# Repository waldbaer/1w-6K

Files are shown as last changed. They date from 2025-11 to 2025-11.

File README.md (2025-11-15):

# 1-Wire 6-Channel Binary Input Board using DS2411

A compact PCB providing six independent binary input channels on a 1-Wire bus, each based on a dedicated [DS2411](doc/ds2411.pdf) unique-ID device.
Prepared for use in standard 35 mm DIN-rail mounting enclosures.

## Hardware

### Schematic

see [1w-6K_schematic.pdf](doc/1w-6K_schematic.pdf).

### Rendering / Photo

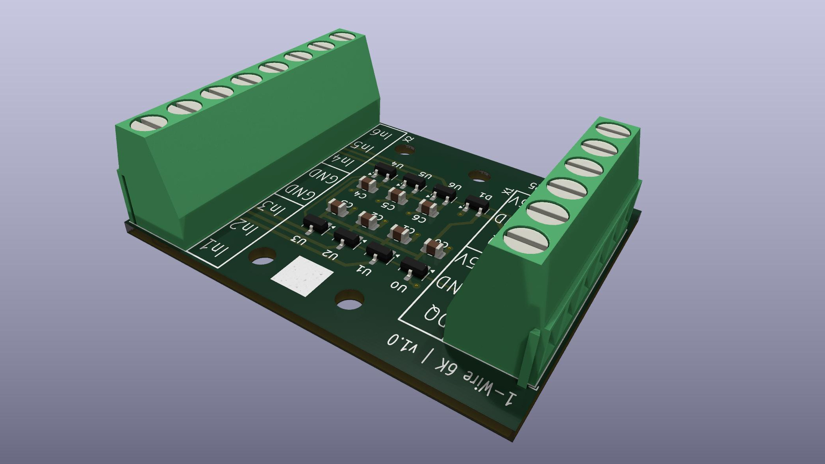
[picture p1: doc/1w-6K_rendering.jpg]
1w-6K rendering

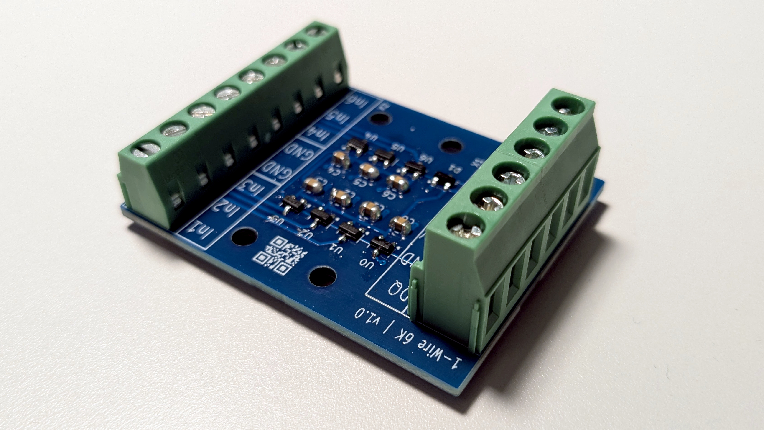
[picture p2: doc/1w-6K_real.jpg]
1w-6K photo


### DIN-rail mounting

The PCB can be mounted to standard 35mm DIN rails using common _25mm DIN Rail Mounting Adapter_ with hole spacing of **12.5mm**.

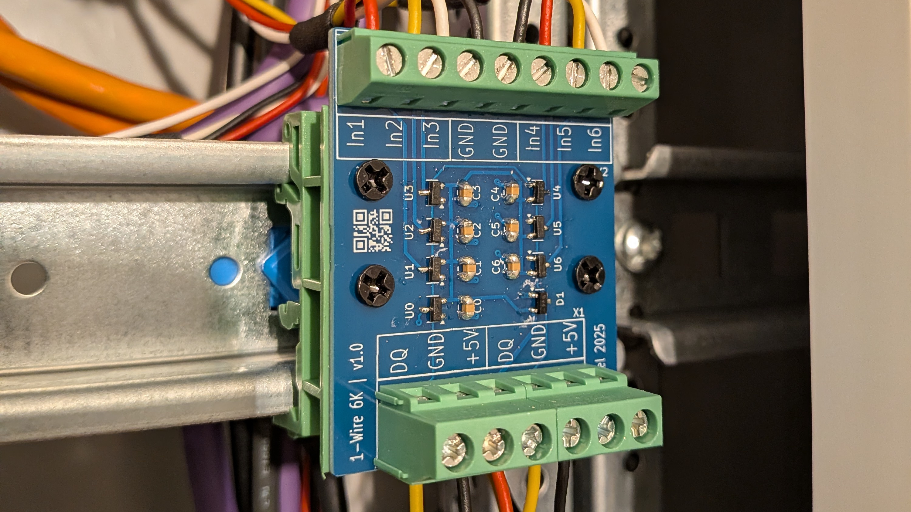
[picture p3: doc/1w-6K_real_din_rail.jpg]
1w-6K photo DIN rail


## Key Features

* 6 × DS2411 devices connected to a the 1-Wire bus
  * Each DS2411 has its GND routed to an individual screw terminal.
  * A binary input channel is considered “closed” when its DS2411 (with factory-programmed 64-bit ROM ID) becomes visible on the bus.

* 1 additional DS2411 permanently connected to the bus.
  * Can be used for alive checks or bus identification

## How It Works

Each binary input corresponds to the GND line of one DS2411.
When GND is connected externally:

* The DS2411 becomes electrically active.
* Its globally unique 64-bit ID appears on the 1-Wire bus.
* The host system interprets this as input active / closed.

### Typical use cases

* Window open / closed detection
* Presence / absence detection

## Development

- PCB designed with [KiCad](https://www.kicad.org/)
- Production files created with KiCad plugin [KiCAD JLCPCB tools](https://github.com/Bouni/kicad-jlcpcb-tools)

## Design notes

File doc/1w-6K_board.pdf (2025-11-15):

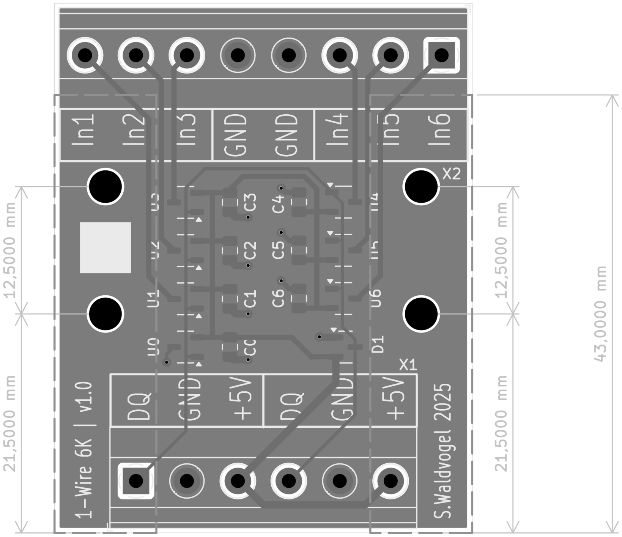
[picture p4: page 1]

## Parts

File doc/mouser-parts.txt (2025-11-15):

Amount  Total Price (EUR)	Single Price (EUR)    Mouser-Nr.:	        Articel Nr.:	    Description.:
15	    € 1,54	          € 1,54                700-DS2411RT&R	    DS2411R+T&R	      Sicherheits-/Authentifizierungs-ICs Sicherheits-/Authentifizierungs-ICs Silicon Serial Number with VCC Input
10	    € 0,071   	      € 0,071               771-BAT54S-T/R	    BAT54S,215	      Schottky Dioden & Gleichrichter Schottky Dioden & Gleichrichter BAT54S/SOT23/TO-236AB
20	    € 0,186   	      € 0,186               581-KAM21KR72A104KU	KAM21KR72A104KU	  Kondensator aus mehreren Keramikschichten MLCC - SMD/SMT Kondensator aus mehreren Keramikschichten MLCC
6	      € 1,18	          € 1,18                651-1890976	        1890976	          Feste Anschlussblöcke Feste Anschlussblöcke 3P 5mm 90DEG
2	      € 3,71	          € 3,71                651-1729076	        1729076	          Feste Anschlussblöcke Feste Anschlussblöcke 8P 5mm 90DEG
6	      € 2,65	          € 2,65                651-3214663	        3214663	          DIN-Schienenanschlussblöcke DIN-Schienenanschlussblöcke PTTBS 1,5/S-KNX
4	      € 0,618   	      € 0,618               651-3214664	        3214664	          Anschlussblocktools und Zubehör Anschlussblocktools und Zubehör D-PTTBS 1,5/S-KNX
2	      € 0,827   	      € 0,827               651-3214699	        3214699	          Anschlussblocktools und Zubehör Anschlussblocktools und Zubehör D-PTTBS 1,5/S
2	      € 0,979   	      € 0,979               651-3022276	        3022276	          Anschlussblocktools und Zubehör Anschlussblocktools und Zubehör CLIPFIX 35-5

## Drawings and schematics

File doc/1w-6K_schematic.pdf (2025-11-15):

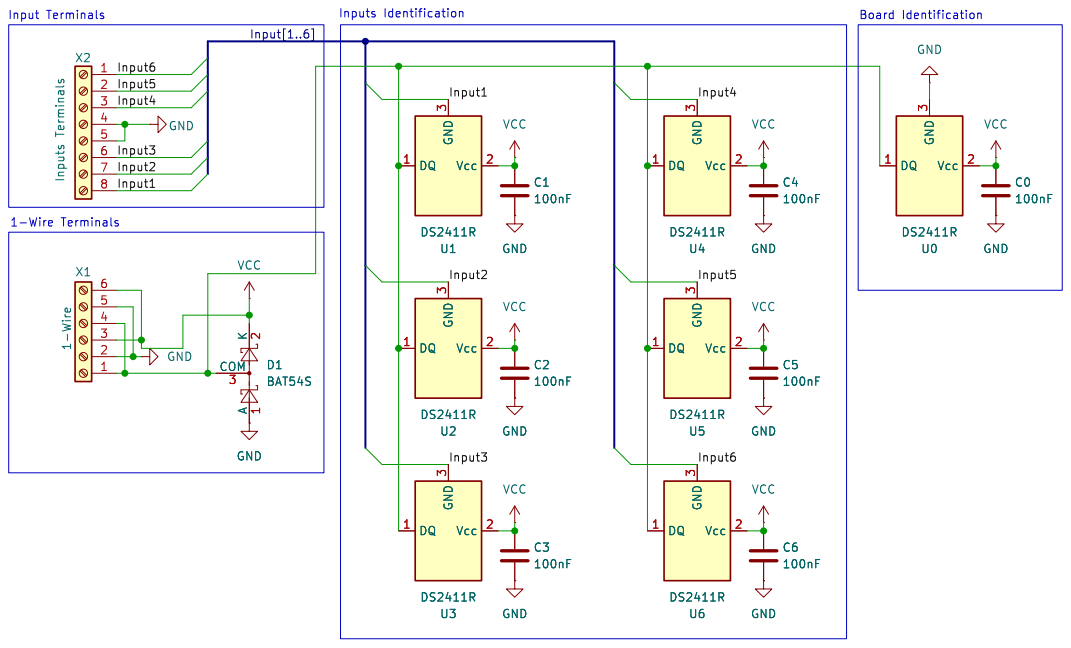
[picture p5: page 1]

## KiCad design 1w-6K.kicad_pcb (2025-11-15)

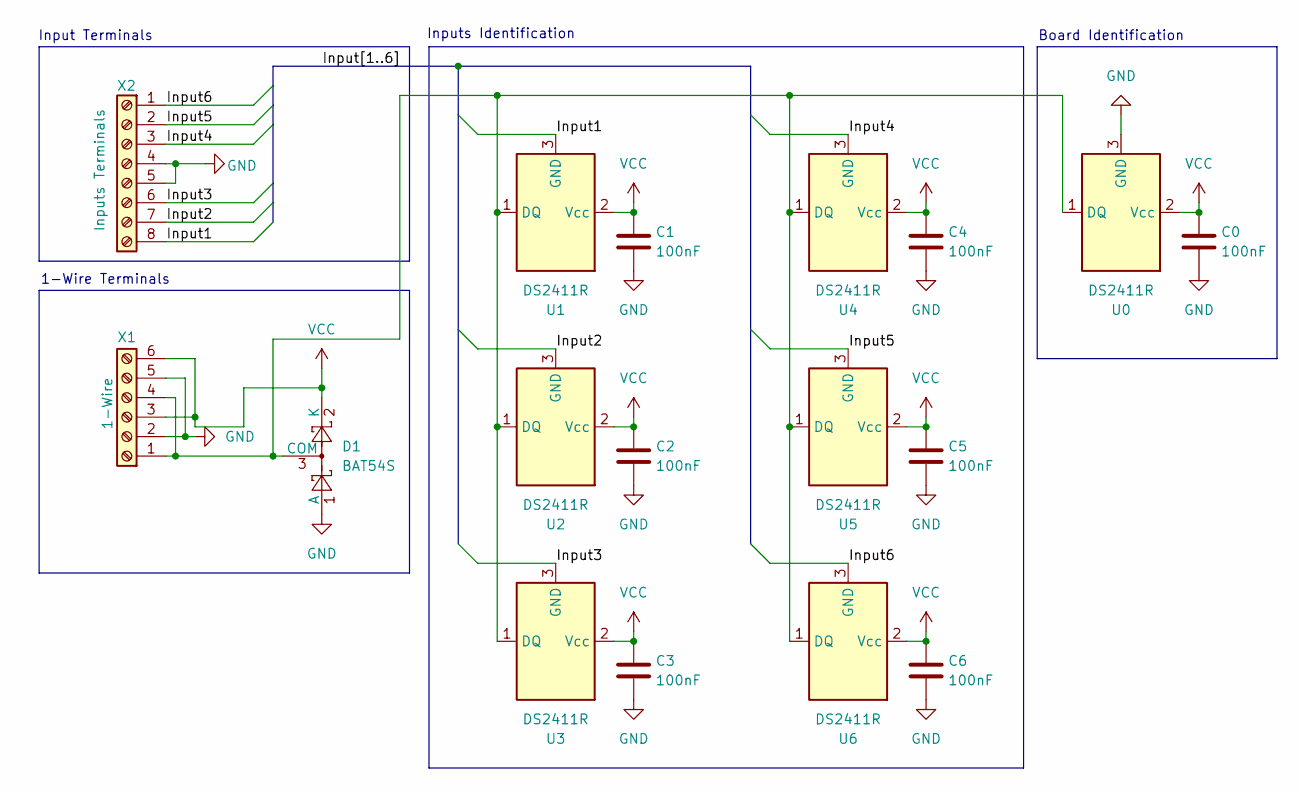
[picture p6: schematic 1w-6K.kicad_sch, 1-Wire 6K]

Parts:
C0, C1, C2, C3, C4, C5, C6: 100nF; C_0805_2012Metric
D1: BAT54S; SOT-23
U0, U1, U2, U3, U4, U5, U6: DS2411R; SOT-23-3
X1: 1-Wire; TerminalBlock_Phoenix_MKDS-1,5-6_1x06_P5.00mm_Horizontal
X2: Inputs Terminals; TerminalBlock_Phoenix_MKDS-1,5-8_1x08_P5.00mm_Horizontal

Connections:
/Input1: U1.3 (GND), X2.8
/Input2: U2.3 (GND), X2.7
/Input3: U3.3 (GND), X2.6
/Input4: U4.3 (GND), X2.3
/Input5: U5.3 (GND), X2.2
/Input6: U6.3 (GND), X2.1
GND: C0.2, C1.2, C2.2, C3.2, C4.2, C5.2, C6.2, D1.1 (A), U0.3 (GND), X1.2, X1.5, X2.4, X2.5
unnamed: D1.3 (COM), U0.1 (DQ), U1.1 (DQ), U2.1 (DQ), U3.1 (DQ), U4.1 (DQ), U5.1 (DQ), U6.1 (DQ), X1.1, X1.4
VCC: C0.1, C1.1, C2.1, C3.1, C4.1, C5.1, C6.1, D1.2 (K), U0.2 (Vcc), U1.2 (Vcc), U2.2 (Vcc), U3.2 (Vcc), U4.2 (Vcc), U5.2 (Vcc), U6.2 (Vcc), X1.3, X1.6

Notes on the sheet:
Inputs Identification
Board Identification
1-Wire Terminals
Input Terminals

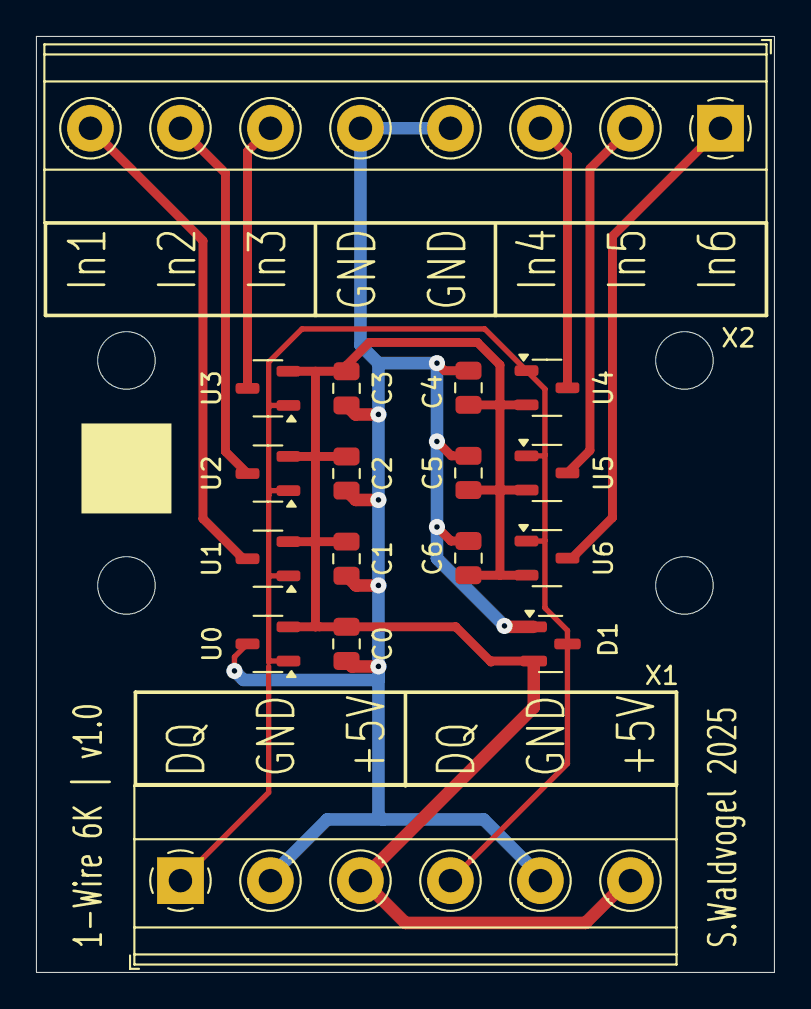
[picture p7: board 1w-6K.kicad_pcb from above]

Board: 2 copper layers, 41.0 x 52.0 mm, 17 parts (0 on the bottom side), 9 nets.

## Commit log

2025-11-15 Publish 1w 6-K in version v1.0
    [1w-6K.kicad_pcb, 1w-6K.kicad_sch]
2025-11-15 Updated schematic copyright & KiCad 8 -> 9
    [1w-6K.kicad_sch]
